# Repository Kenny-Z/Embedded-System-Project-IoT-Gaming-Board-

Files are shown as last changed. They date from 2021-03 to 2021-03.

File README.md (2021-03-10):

## WiFi-IoT-Gaming-Board
ESE516 Project Chen Chen and Wuji Zhang
This is a course project for ESE516:IoT Edge Computing. We are trying to make a Gaming Board from hardware to software.
The repository consists of the altium project, and the software project is coming along the semester.
## 3D model for Altium Project
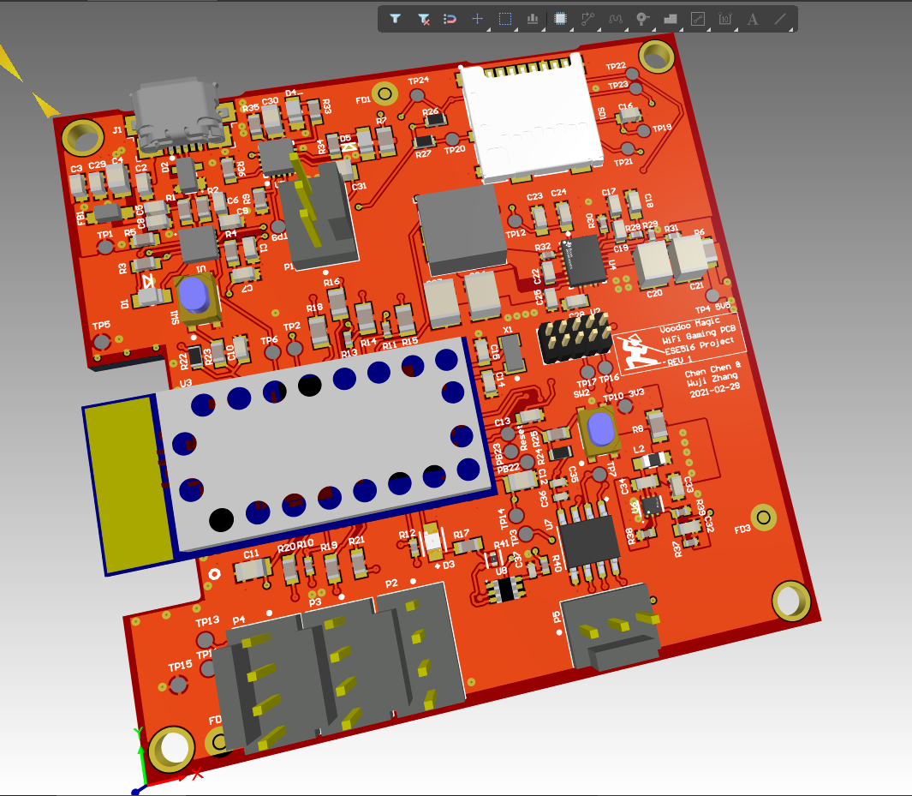
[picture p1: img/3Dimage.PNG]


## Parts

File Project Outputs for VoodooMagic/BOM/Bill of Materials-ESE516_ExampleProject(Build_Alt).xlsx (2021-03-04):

Line # | Description | Designator | Quantity | Name | Manufacturer 1 | Manufacturer Part Number 1 | Manufacturer Lifecycle 1 | Supplier 1 | Supplier Part Number 1 | Supplier Unit Price 1 | Supplier Subtotal 1
 |  |  | 0 | Keypad | DNP | DNP | DNP | Digi-Key | 1528-2712-ND | 0 | 0
 |  |  | 0 | OLED Screen | DNP | DNP | DNP | Digi-Key | 1568-1819-ND | 0 | 0
16 | CAP 100nF 16V ±10% 0603 (1608 Metric) Thickness 1mm SMD | C1, C3, C7, C16 | 4 | CAP 100nF 16V 0603(1608) | Yageo | CC0603KRX7R7BB104 | Volume Production | Digi-Key | 311-1088-6-ND | 0.1 | 0.4
7 | CAP 10nF 16V ±10% 0603 (1608 Metric) Thickness 1mm SMD | C2 | 1 | CAP 10nF 16V 0603(1608) | Yageo | CC0603KRX7R7BB103 | Volume Production | Digi-Key | 311-3369-1-ND | 0.1 | 0.1
5 | CAP 4.7uF 16V -20% to +80% 0805 (2012 Metric) Thickness 1.45mm SMD | C4, C30, C31 | 3 | CAP 4.7uF 16V 0805(2012) | Yageo | CC0805KKX7R8BB475 | Volume Production | Digi-Key | 311-1885-6-ND | 0.42 | 1.26
 | CAP 100pF 50V ±20% 0603 (1608 Metric) Thickness 1mm SMD | C5, C6, C8, C9, C17, C19 | 6 | CAP 100pF 50V 0603(1608) | KEMET | C0603C101M5GACTU | Volume Production | Digi-Key | 399-8981-6-ND | 0.1 | 0.6
4 | CAP 1uF 16V ±5% 0603 (1608 Metric) Thickness 1mm SMD | C10, C13, C29 | 3 | CAP 1uF 16V 0603(1608) | Yageo | CC0603KRX7R7BB105 | Volume Production | Digi-Key | 311-1446-6-ND | 0.15 | 0.45
8 | CAP 10uF 16V ±10% 0805 (2012 Metric) Thickness 1.45mm SMD | C11, C12 | 2 | CAP 10uF 16V 0805(2012) | Kyocera AVX | 0805YD106KAT2A | Volume Production | Digi-Key | 478-5165-1-ND | 0.39 | 0.78
9 | CAP 18pF 16V ±5% 0603 (1608 Metric) Thickness 1mm SMD | C14, C15 | 2 | CAP 18pF 16V 0603(1608) | KEMET | C0603C180J4GACTU | Volume Production | Digi-Key | 399-11141-1-ND | 0.25 | 0.5
 | CAP 1nF 10V ±1% 0603 (1608 Metric) Thickness 1mm SMD | C18 | 1 | CAP 1nF 10V 0603(1608) | Yageo | CC0603KRX7R7BB102 | Volume Production | Digi-Key | 311-4063-1-ND | 0.1 | 0.1
 | Cap Ceramic, 47 uF, +/- 10%, -55 to 85 degC, 2-Pin SMD (1210), RoHS, Tape and Reel | C20, C21, C26, C27 | 4 | GRM32ER61C476KE15L | Murata | GRM32ER61C476KE15L | Volume Production | Digi-Key | 490-6539-6-ND | 0.63 | 2.52
 | CAP 100nF 10V ±5% 0603 (1608 Metric) Thickness 1mm SMD | C22, C25 | 2 | CAP 100nF 10V 0603(1608) | Yageo | CC0402KRX7R7BB104 | Volume Production | Digi-Key | 311-1338-6-ND | 0.1 | 0.2
 | CAP 1uF 10V ±10% 0603 (1608 Metric) Thickness 1mm SMD | C23, C24 | 2 | CAP 1uF 10V 0603(1608) | Yageo | CC0603KPX7R8BB105 | Unknown | Digi-Key | 13-CC0603KPX7R8BB105DKR-ND | 0.26 | 0.52
 | CAP 8.2nF 10V ±5% 0603 (1608 Metric) Thickness 1mm SMD | C28 | 1 | CAP 8.2nF 10V 0603(1608) | Yageo | CC0603KRX7R9BB822 | Volume Production | Digi-Key | 311-1811-1-ND | 0.1 | 0.1
 | CAP 120pF 10V ±10% 0603 (1608 Metric) Thickness 1mm SMD | C32 | 1 | CAP 120pF 10V 0603(1608) | Yageo | CC0603KRX7R9BB121 | Volume Production | Digi-Key | 311-4094-1-ND | 0.1 | 0.1
 | Chip Capacitor, 22 uF, +/- 20%, 10 V, -55 to 85 degC, 0603 (1608 Metric), RoHS, Tape and Reel | C33 | 1 | C1608X5R1A226M080AC | TDK | C1608X5R1A226M080AC | Volume Production | Digi-Key | 445-9077-6-ND | 0.49 | 0.49
 | CAP 4.7uF 10V ±10% 0603 (1608 Metric) Thickness 0.55mm SMD | C34 | 1 | CAP 4.7uF 10V 0603(1608) | Yageo | CC0805KKX7R9BB225 | Volume Production | Digi-Key | 311-3420-6-ND | 1.06 | 1.06
 | CAP 1uF 10V ±10% 0402 (1005 Metric) Thickness 0.6mm SMD | C35 | 1 | CAP 1uF 10V 0402(1005) | Yageo | CC0603KRX7R7BB105 | Volume Production | Digi-Key | 311-1446-6-ND | 0.15 | 0.15
 | CAP 100nF 10V ±5% 0402 (1005 Metric) Thickness 0.6mm SMD | C36, C37 | 2 | CAP 100nF 10V 0402(1005) | Yageo | CC0603KRX7R8BB104 | Volume Production | Digi-Key | 311-1341-1-ND | 0.1 | 0.2
30 | LED Uni-Color Red, 100 mW, 200 mA, -55 to 85 degC, 2-Pin SMD, RoHS, Tape and Reel | D1, D4 | 2 | LTST-C170CKT | Vishay Lite-On | LTST-C170CKT | Volume Production | Digi-Key | 160-1176-1-ND | 0.35 | 0.7
34 | Ultra Low Capacitance Double Rail-to-Rail ESD Protection Diode, 5.5 V, 1 pF, -40 to 85 degC, 4-Pin SOT143B, RoHS, Tape and Reel | D2 | 1 | PRTR5V0U2X,215 | Nexperia | PRTR5V0U2X,215 |  | Digi-Key | 1727-3884-6-ND | 0.48 | 0.48
 | LED RED DIFFUSED 0805 SMD | D3 | 1 | LH R974-LP-1 | Osram Opto | LH R974-LP-1 | Volume Production | Digi-Key | 475-1415-1-ND | 0.26 | 0.26
31 | LED Uni-Color Green, 100 mW, 120 mA, -55 to 85 degC, 2-Pin SMD, RoHS, Tape and Reel | D5 | 1 | LTST-C170GKT | Vishay Lite-On | LTST-C170GKT | Volume Production | Digi-Key | 160-1179-1-ND | 0.3 | 0.3
24 | Chip Ferrite Bead for Power Lines, 220 Ohm, 2000 mA, -55 to 125 degC, 2 x 1.25 x 1.05 mm SMD, Tape and Reel | FB1 | 1 | BLM21PG221SN1D | Murata | BLM21PG221SN1D | Volume Production | Digi-Key | 490-1054-6-ND | 0.1 | 0.1
39 | Connector; USBMicro-B,Reverse type, SMT; 5 Position; Right Angle | J1 | 1 | ZX62R-B-5P | Hirose | ZX62R-B-5P(30) | Volume Production | Digi-Key | H125274CT-ND | 1.02 | 1.02
 | BOURNS - SRP6540-1R0M - Cewka mocy (SMD), 1 µH, 12 A, Osloniete, 13.5 A, Seria SRP6540, 7.2mm x 6.5mm x 4mm | L1 | 1 | 1uH | Bourns | SRP6540-1R0M | Volume Production | Digi-Key | SRP6540-1R0MCT-ND | 1.36 | 1.36
 | FIXED IND 470NH 1.2A 90 MOHM SMD | L2 | 1 | 470nH | Vishay Dale | IHLP1212AEERR47M11 | Volume Production | Digi-Key | 541-1330-6-ND | 1.26 | 1.26
20 | Male Header, Pitch 2.54 mm, 1 x 3 Position, Height 10.03 mm, Tail Length 3.56 mm, -55 to 105 degC | P1, P5 | 2 | 640456-3 | Molex | 22-11-2032 | Volume Production | Digi-Key | WM2701-ND | 0.53 | 1.06
 | Male Header, Pitch 2.54 mm, 1 x 4 Position, Height 10.03 mm, Tail Length 3.56 mm, RoHS, Bulk | P2, P3, P4 | 3 | 640456-4 | TE Connectivity | 640456-4 | Volume Production | Digi-Key | A1922-ND | 0.24 | 0.72
1 | 0.1" Pad | PB22, PB23, Reset, TP3, TP4 5V5, TP7, TP10 3V3, TP11, TP12, TP13, TP14, TP15, TP16, TP17, TP19, TP20, TP21, TP22, TP23, TP24 | 20 | 0.1" Pad | DNP | DNP | DNP | DNP | DNP | DNP
11 | 27R 0.1W 1% 0603 (1608 Metric) SMD | R1, R2, R19, R20, R21 | 5 | 27R 1% 0603(1608) | Stackpole Electronics | RMCF0603JT27R0 | Volume Production | Digi-Key | RMCF0603JT27R0DKR-ND | 0.014 | 0.14
3 | 1K 0.1W 1% 0603 (1608 Metric) SMD | R3, R5, R9, R17, R33, R34 | 6 | 1K 1% 0603(1608) | Stackpole Electronics | RMCF0603FG1K00 | Volume Production | Digi-Key | RMCF0603FG1K00CT-ND | 0.016 | 0.16
28 | Jumper 0603 (1608 Metric) | R4 | 1 | Jumper 0603(1608) | Yageo | RC0603JR-070RL | Volume Production | Digi-Key | 311-0.0GRCT-ND | 0.1 | 0.1
29 | Jumper 0805 (2012 Metric) | R6, R7, R8, R14, R15, R16, R18 | 7 | Jumper 0805(2012) | Yageo | RC0805JR-070RL | Volume Production | Digi-Key | 311-0.0ARDKR-ND | 0.031 | 0.31
 | 4K7 0.063W 1% 0402 (1005 Metric) SMD | R10, R11, R12, R13 | 4 | 4K7 1% 0402(1005) | Stackpole Electronics | RMCF0402FT4K70 | Volume Production | Arrow Electronics | RMCF0402FT4K70 | 0.021 | 0.084
 | Chip Resistor, 10 KOhm, +/- 1%, 0.1 W, -55 to 155 degC, 0603 (1608 Metric), RoHS, Tape and Reel | R22, R24, R26, R27 | 4 | ERJ3EKF1002V | Stackpole Electronics | RMCF0402FT10K0 | Volume Production | Digi-Key | RMCF0402FT10K0CT-ND | 0.014 | 0.14
17 | 100R 0.1W 1% 0603 (1608 Metric) SMD | R23, R25 | 2 | 100R 1% 0603(1608) | Stackpole Electronics | RMCF0603FG100R | Volume Production | Digi-Key | RMCF0603FG100RCT-ND | 0.016 | 0.16
 | 23K7 0.063W 1% 0402 (1005 Metric) SMD | R28 | 1 | 23K7 1% 0402(1005) | Stackpole Electronics | RMCF0603FT23K7 | Volume Production | Digi-Key | RMCF0603FT23K7DKR-ND | 0.1 | 0.1
 | 86K6 0.063W 1% 0402 (1005 Metric) SMD | R29 | 1 | 86K6 1% 0402(1005) | Stackpole Electronics | RMCF0402FT86K6 | Volume Production | Digi-Key | RMCF0402FT86K6DKR-ND | 0.1 | 0.1
 | 140K 0.063W 1% 0402 (1005 Metric) SMD | R30 | 1 | 140K 1% 0402(1005) | Stackpole Electronics | RMCF0402FT140K | Volume Production | Digi-Key | 738-RMCF0402FT140KCT-ND | 0.1 | 0.1
 | 309K 0.063W 1% 0402 (1005 Metric) SMD | R31 | 1 | 309K 1% 0402(1005) | Stackpole Electronics | RMCF0402FT309K | Volume Production | Digi-Key | RMCF0402FT309KDKR-ND | 0.1 | 0.1
 | 453K 0.063W 1% 0402 (1005 Metric) SMD | R32, R37 | 2 | 453K 1% 0402(1005) | Stackpole Electronics | RMCF0402FT453K | Volume Production | Digi-Key | RMCF0402FT453KDKR-ND | 0.014 | 0.14
2 | 1K13 0.1W 1% 0603 (1608 Metric) SMD | R35, R36 | 2 | 1K13 1% 0603(1608) | Stackpole Electronics | RMCF0603FT1K13 | Volume Production | Digi-Key | RMCF0603FT1K13DKR-ND | 0.016 | 0.16
 | 100K 0.063W 1% 0402 (1005 Metric) SMD | R38, R39 | 2 | 100K 1% 0402(1005) | Stackpole Electronics | RMCF0402FT100K | Volume Production | Digi-Key | RMCF0402FT100KDKR-ND | 0.014 | 0.14
 | 10R 0.063W 1% 0402 (1005 Metric) SMD | R40 | 1 | 10R 1% 0402(1005) | Stackpole Electronics | RMCF0402JT10R0 | Volume Production | Arrow Electronics | RMCF0402JT10R0 | 0.0132 | 0.0132
 | RES Thick Film, 10kΩ, 1%, 0.063W, 100ppm/°C, 0402 | R41 | 1 | CRCW040210K0FKEE | Stackpole Electronics | RMCF0402FT10K0 | Volume Production | Digi-Key | RMCF0402FT10K0DKR-ND | 0.1 | 0.1
19 | Micro SD Card, RA, -25 to 85 degC, 8-Pin SMD, RoHS, Tape and Reel | SD1 | 1 | 104031-0811 | Molex | 1040310811 | Volume Production | Digi-Key | WM6357DKR-ND | 1.83 | 1.83
 | SWITCH TACTILE SPST-NO 0.05A 16V | SW1, SW2 | 2 | PTS810 SJG 250 SMTR LFS | ITT C&K | PTS810SJG250SMTRLFS | Volume Production | Digi-Key | CKN10504CT-ND | 0.37 | 0.74
27 | FT234XD USB to BASIC UART IC, -40 to +85 degC, 12-Pin DFN, Pb-Free, Tape and Reel | U1 | 1 | FT234XD-R | FTDI | FT234XD-R | Volume Production | Digi-Key | 768-1178-1-ND | 2.04 | 2.04
21 | CONN HEADER 10POS UNSHD VERT T/H | U2 | 1 | 20021111-00010T4LF | Amphenol FCI | 20021111-00010T4LF | Volume Production | Digi-Key | 609-3712-ND | 0.73 | 0.73
36 | RF TXRX MODULE WIFI TRACE ANT | U3 | 1 | SAMW25H18-MR510PB | Microchip / Atmel | ATSAMW25H18-MR510PB | Volume Production | Digikey | ATSAMW25H18-MR510PB-ND
 | IC REG BOOST ADJ 10A 20VQFN | U4 | 1 | TPS61088RHLT | Texas Instruments | TPS61088RHLT | New Product | Digi-Key | 296-42129-1-ND | 4.55 | 4.55
 | USB-Friendly Li-Ion Battery Charger and Power-Path Management IC, Vout 5.5 V, 4.3 V, -40 to 85 degC, 16-pin QFN (RGT), Green (RoHS & no Sb/Br) | U5 | 1 | BQ24075RGTR | Texas Instruments | BQ24075RGTR | Volume Production | Digi-Key | 296-38874-6-ND | 2.19 | 2.19
 | 2.4V-5.5V input, 4A step-down converter with 1% Accuracy in 1.5mm x 1.5mm QFN 6-VSON-HR -40 to 125 | U6 | 1 | TPS62827DMQR | Texas Instruments | TPS62827DMQR |  | Digi-Key | 296-TPS62827DMQRCT-ND
 | Sensor Controller Capacitive 3-CH I2C 8-Pin SOIC T/R | U7 | 1 | I2C Touch Sensor | Microchip | CAP1203-1-SN-TR | Not Recommended for New Design | Digi-Key | CAP1203-1-SN-CT-ND | 0.55 | 0.55
 | HIGH ACCURACY AMBIENT LIGHT SENS | U8 | 1 | I2C Light Sensor | Vishay Semiconductors | VEML6030-GS15 |  | Digi-Key | VEML6030-GS15CT-ND | 2 | 2
22 | Crystal, 32.768 kHz, 12.5 pF, -40 to 85 degC, SMD Low Profile 3.2 x 1.5 x 0.9 mm, Tape and Reel | X1 | 1 | ABS07-32.768KHz-T | Micro Crystal | CC7V-T1A-32.768KHZ-12.5PF-20PPM-TA-QC |  | Digi-Key | 2195-CC7V-T1A-32.768KHZ-12.5PF-20PPM-TA-QCCT-ND | 0.61 | 0.61

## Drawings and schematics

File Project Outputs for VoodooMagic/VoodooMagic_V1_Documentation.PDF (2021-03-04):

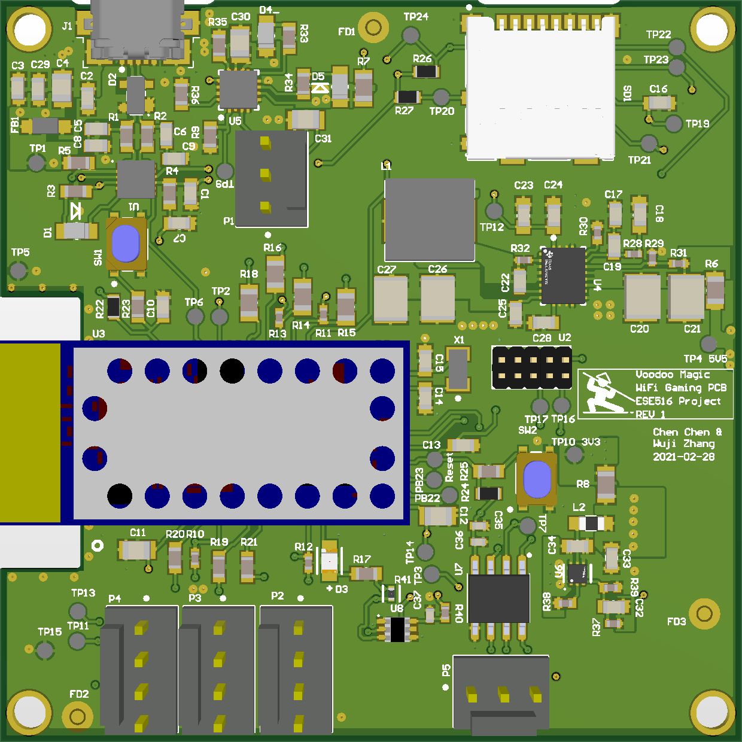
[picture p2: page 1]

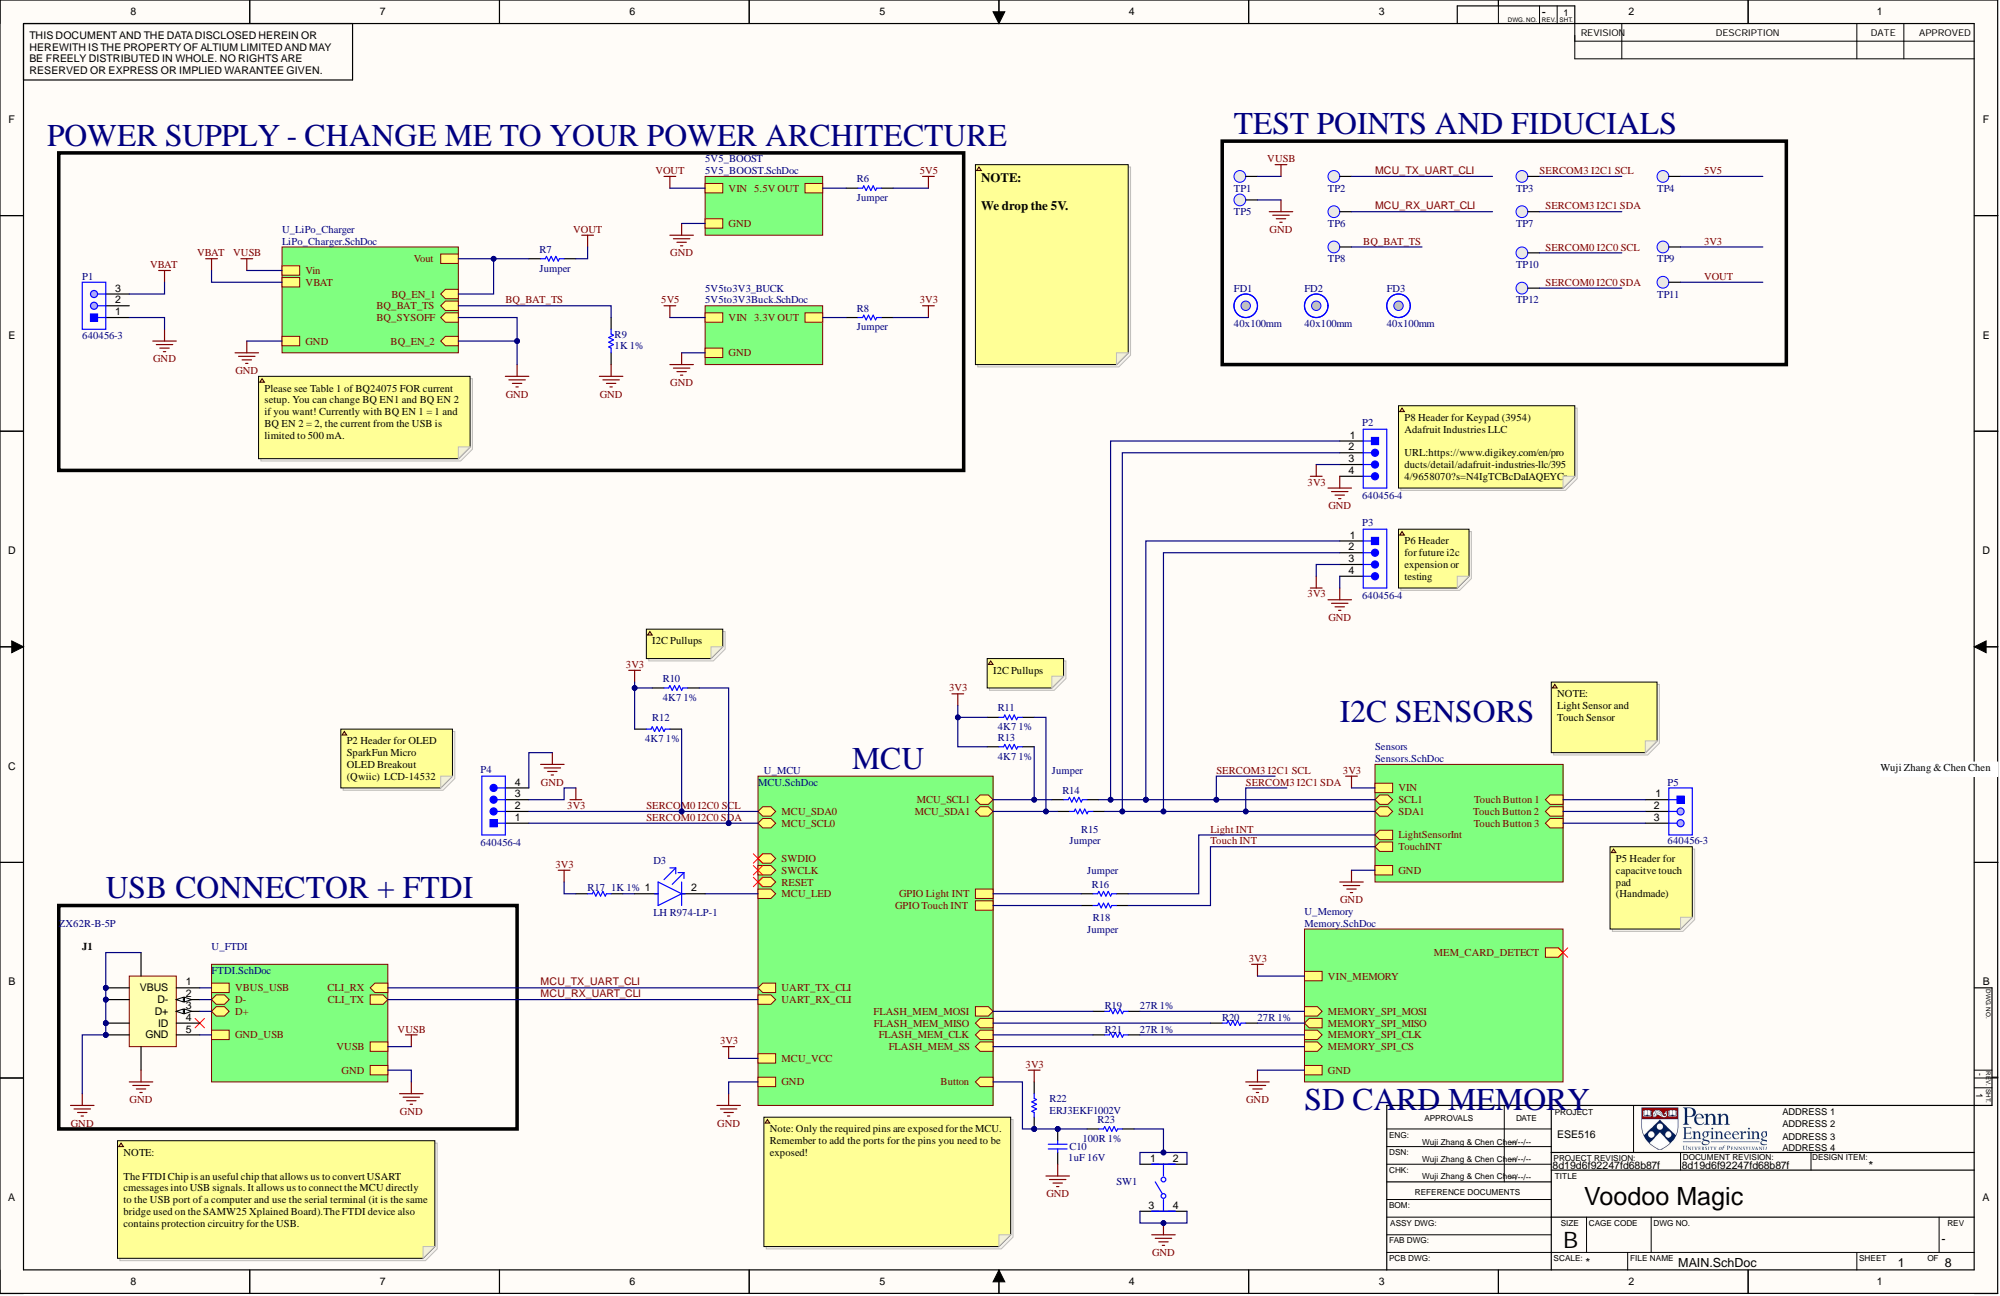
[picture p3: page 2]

DWG. NO. | -REV. | 1 SHT.

THIS DOCUMENT AND THE DATA DISCLOSED HEREIN OR HEREWITH IS THE PROPERTY OF ALTIUM LIMITED AND MAY BE FREELY DISTRIBUTED IN WHOLE. NO RIGHTS ARE RESERVED OR EXPRESS OR IMPLIED WARANTEE GIVEN. POWER SUPPLY - CHANGE ME TO YOUR POWER ARCHITECTURE | TEST POINTS AND FIDUCIALS | REVISION | DESCRIPTION | DATE | APPROVED

GND
Please see Table 1 of BQ24075 FOR current
setup. You can change BQ EN1 and BQ EN 2
if you want! Currently with BQ EN 1 = 1 and
BQ EN 2 = 2, the current from the USB is
limited to 500 mA.

URL:https://www.digikey.com/en/pro
ducts/detail/adafruit-industries-llc/395
4/9658070?s=N4IgTCBcDaIAQEYCs

SERCOM3 I2C1 SCL | 3

Wuji Zhang & Chen Chen

REV. SHT. DWG. NO.

Note: Only the required pins are exposed for the MCU.
Remember to add the ports for the pins you need to be
exposed!

DSN: Wuji Zhang & Chen Chen | --/--/--

8d19d6f92247fd68b87f | DOCUMENT REVISION: 8d19d6f92247fd68b87f | DESIGN ITEM: * PROJECT REVISION:

CHK: Wuji Zhang & Chen Chen | --/--/--

The FTDI Chip is an useful chip that allows us to convert USART
cmessages into USB signals. It allows us to connect the MCU directly
to the USB port of a computer and use the serial terminal (it is the same
bridge used on the SAMW25 Xplained Board).The FTDI device also
contains protection circuitry for the USB.

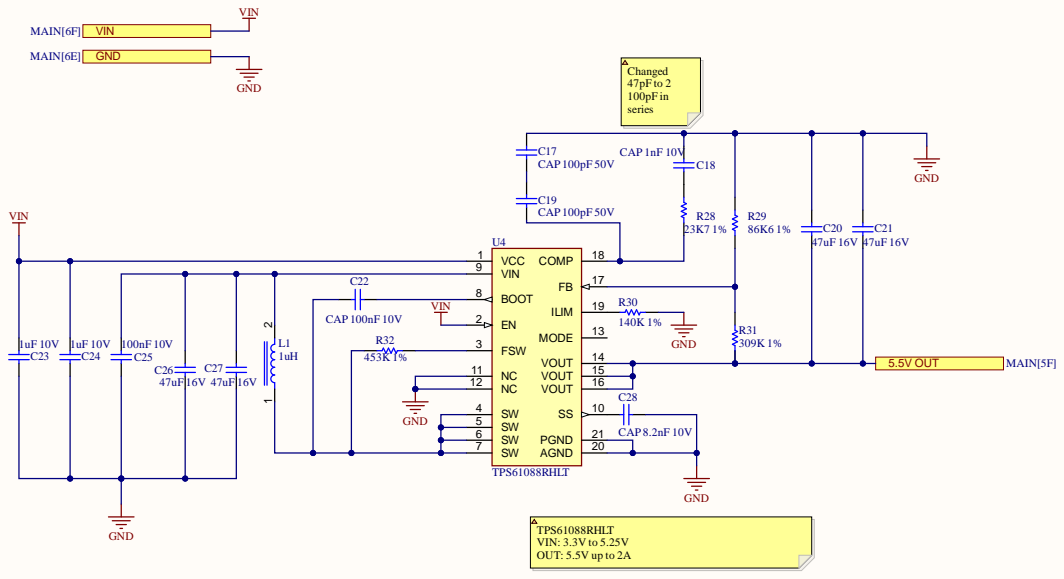
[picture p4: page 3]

DWG. NO. | -REV. | 2 SHT.

THIS DOCUMENT AND THE DATA DISCLOSED HEREIN OR HEREWITH IS THE PROPERTY OF ALTIUM LIMITED AND MAY BE FREELY DISTRIBUTED IN WHOLE. NO RIGHTS ARE RESERVED OR EXPRESS OR IMPLIED WARANTEE GIVEN. | | REVISION | DESCRIPTION | DATE | APPROVED

R32
453K 1% | NC 11

REV. SHT. DWG. NO.

DATE | PROJECT * | ADDRESS 1 ADDRESS 2 APPROVALS ADDRESS 3 ADDRESS 4

ENG: * | --/--/--

DSN: Wuji Zhang | --/--/--

8d19d6f92247fd68b87f | DOCUMENT REVISION: 8d19d6f92247fd68b87f | DESIGN ITEM: * PROJECT REVISION:

CHK: Wuji Zhang | --/--/--

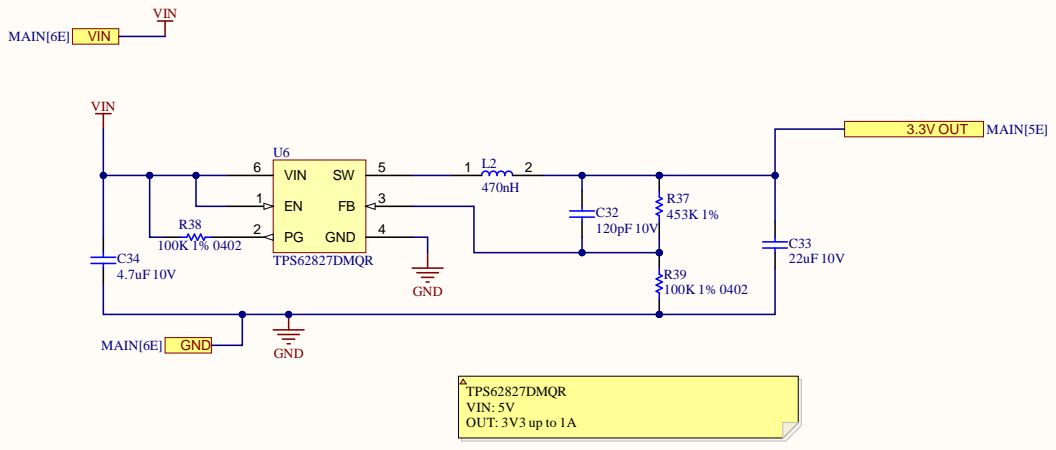
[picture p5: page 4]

DWG. NO. | -REV. | 3 SHT.

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

REV. SHT. DWG. NO.

DATE | PROJECT * | ADDRESS 1 ADDRESS 2 APPROVALS ADDRESS 3 ADDRESS 4

ENG: Wuji Zhang | --/--/--

DSN: Wuji Zhang | --/--/--

8d19d6f92247fd68b87f | DOCUMENT REVISION: 8d19d6f92247fd68b87f | DESIGN ITEM: * PROJECT REVISION:

CHK: Wuji Zhang | --/--/--

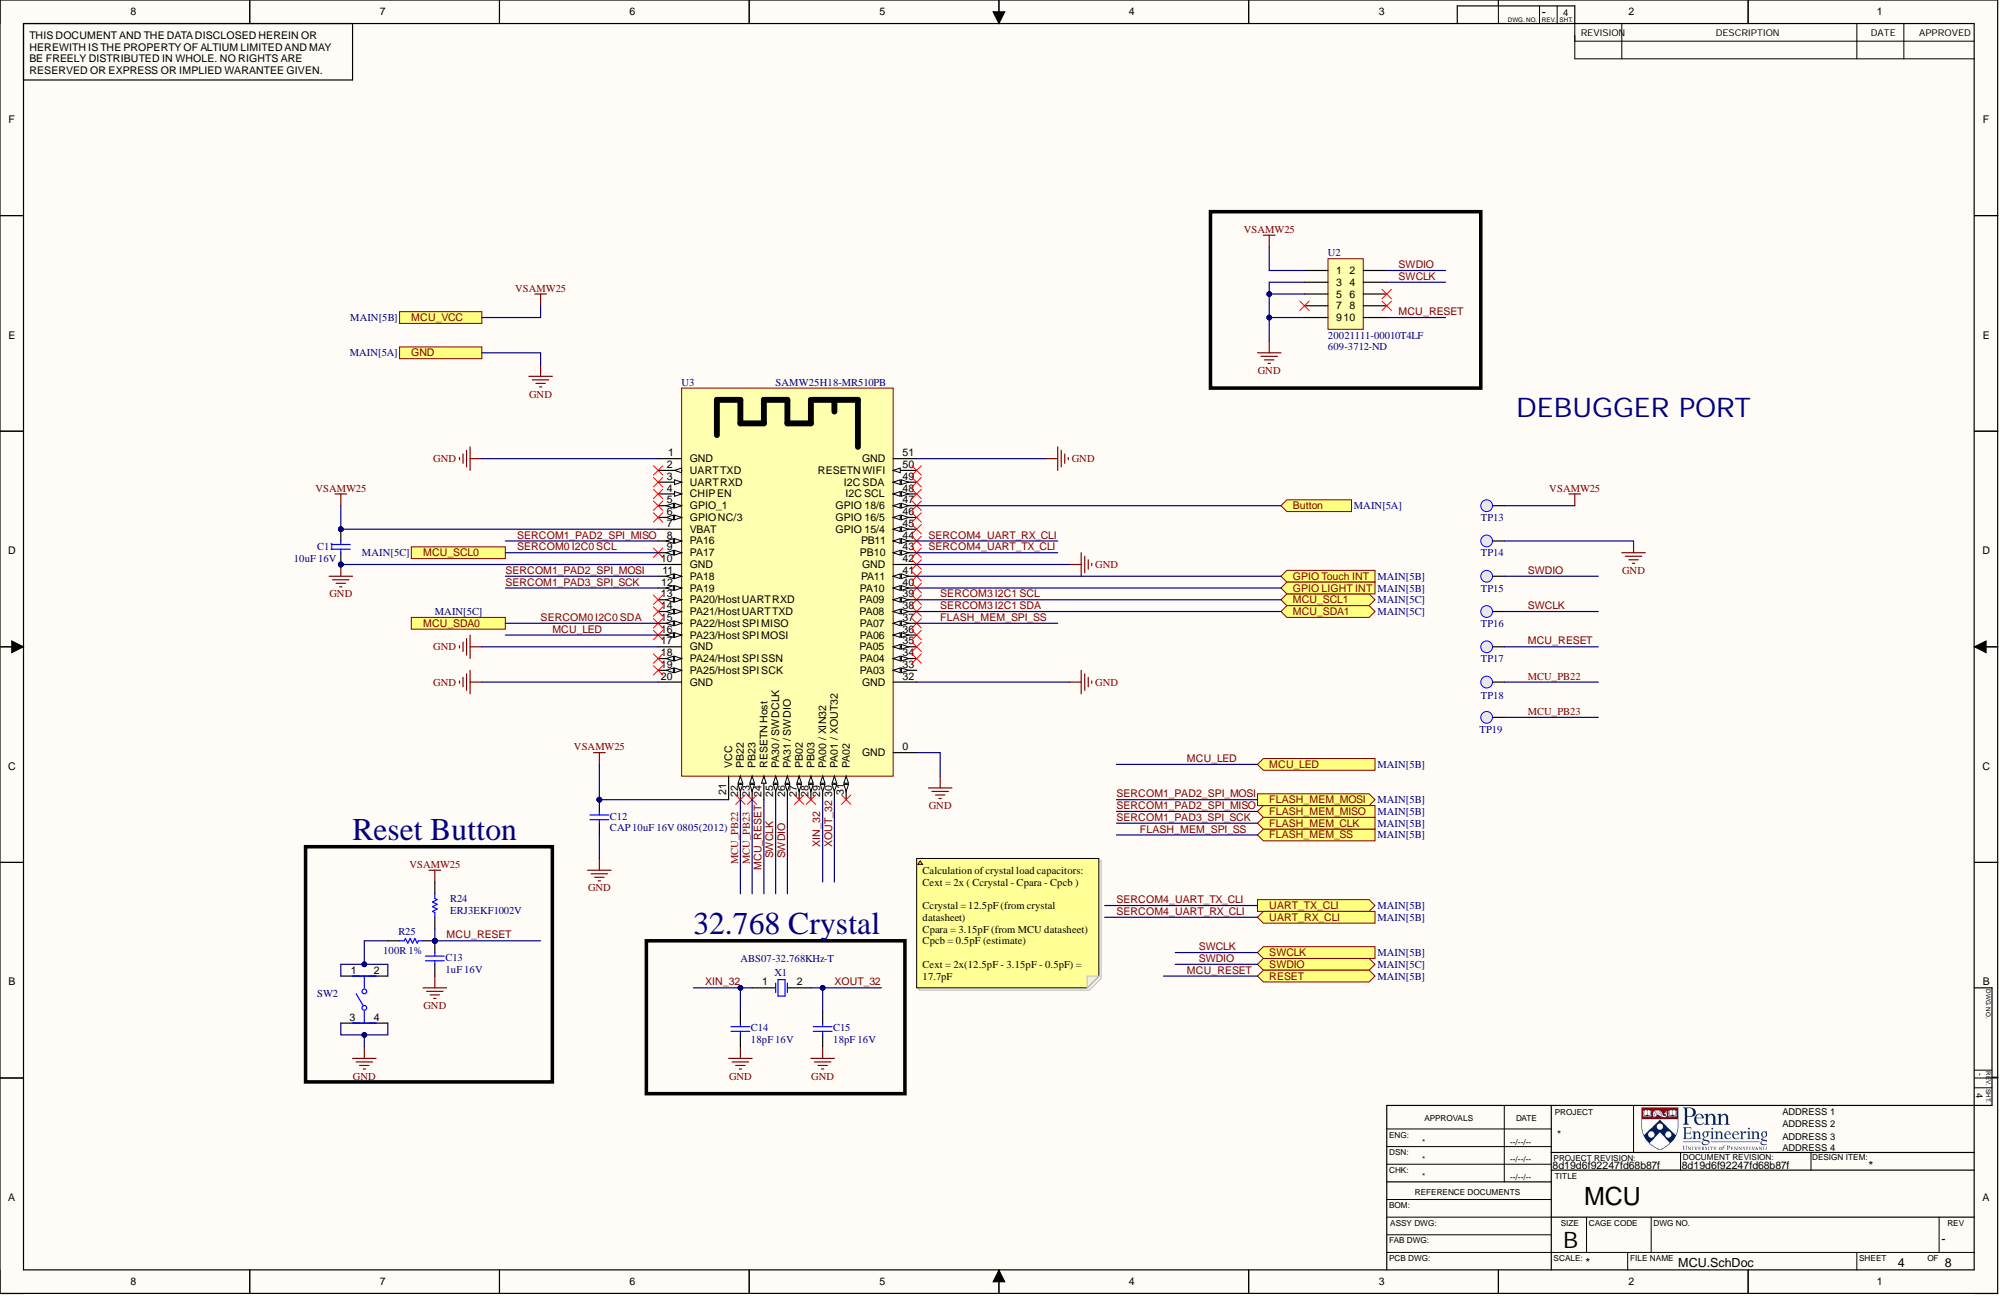
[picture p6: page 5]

DWG. NO. | -REV. | 4 SHT.

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

GPIO Touch INT MAIN[5B]
GPIO LIGHT INT MAIN[5B]

Calculation of crystal load capacitors:
Cext = 2x ( Ccrystal - Cpara - Cpcb )

Ccrystal = 12.5pF (from crystal
datasheet)
Cpara = 3.15pF (from MCU datasheet)
Cpcb = 0.5pF (estimate)

REV. SHT. DWG. NO.

DATE | PROJECT * | ADDRESS 1 ADDRESS 2 APPROVALS ADDRESS 3 ADDRESS 4

ENG: * | --/--/--

DSN: * | --/--/--

8d19d6f92247fd68b87f | DOCUMENT REVISION: 8d19d6f92247fd68b87f | DESIGN ITEM: * PROJECT REVISION:

CHK: * | --/--/--

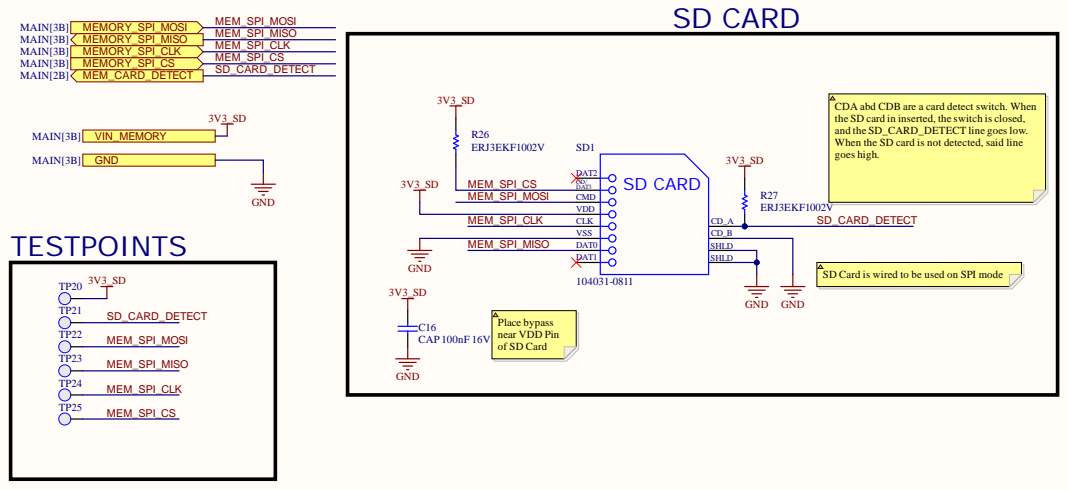
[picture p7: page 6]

DWG . N O . | -R E V | 5 . S H T.

T H IS DOC U MEN T AN D T HE ATA ISCLOSED HEREI N OR HEREW I T H IS T HE PROPER TY OF ALT I U M LI M I TED AN M AY BE F REELY IST R IBU TED I N W HOLE. NO R IGH TS ARE RESERVED OR EXPRESS OR I MPLIED WARAN TEE GIVEN . | | REVISI O N | DESC R IPT I O N | DAT E | APPR OVED

REV. SHT. DWG. NO.

DATE | PRO JECT * | AD D RESS 1 2 APPROVALS AD D RESS AD D RESS 3 AD D RESS 4

ENG : Wu j i Zh a n g | --/--/--

DSN: Wu j i Zh a n g | --/--/--

8d19d6f92247fd68b 8 7 f | DOCUMENT REVISION: 8d19d6f92247fd68b 8 7 f | DESIGN ITEM: * PROJECT REVISION:

CHK: Wu j i Zh a n g | --/--/--

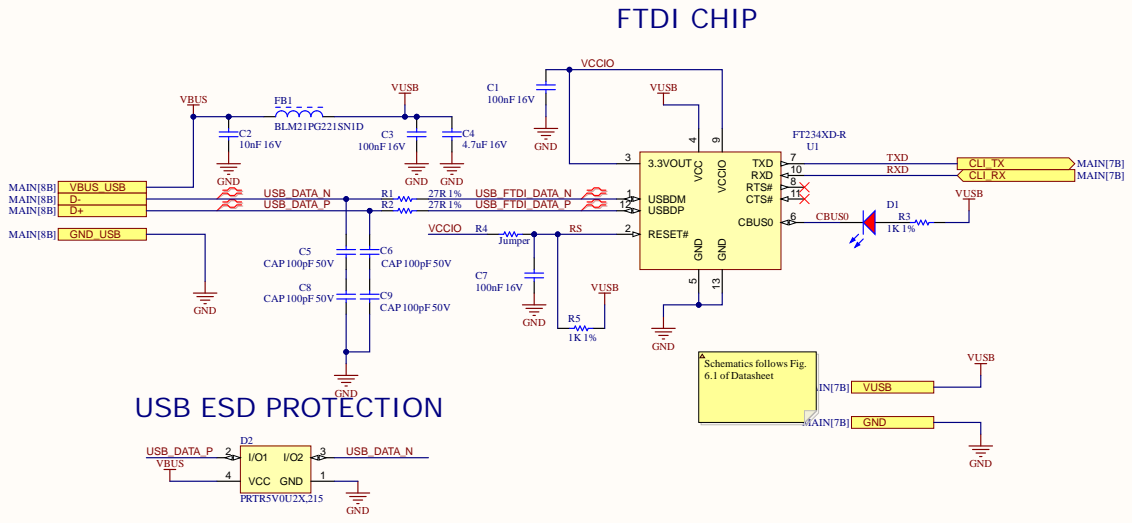
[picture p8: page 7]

DWG. NO. | -REV. | 6 SHT.

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

REV. SHT. DWG. NO.

DATE | PROJECT * | ADDRESS 1 ADDRESS 2 APPROVALS ADDRESS 3 ADDRESS 4

ENG: Wuji Zhang | --/--/--

DSN: Wuji Zhang | --/--/--

8d19d6f92247fd68b87f | DOCUMENT REVISION: 8d19d6f92247fd68b87f | DESIGN ITEM: * PROJECT REVISION:

CHK: Wuji Zhang | --/--/--

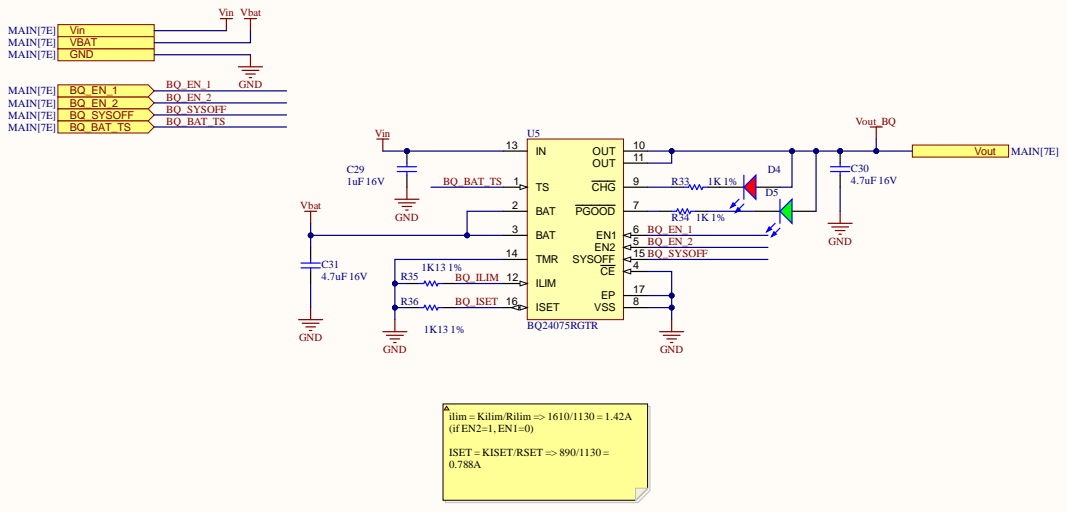
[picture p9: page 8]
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

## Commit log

2021-02-07 Version1 A2Q2
    Wuji Zhang
    [ESE516A2.PcbLib, ESE516A2.SchLib, ESE516_ExampleLayoutProject_.PrjPcb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]
2021-02-09 123
    123
    [5.SchDoc, 5V5_BOOST.SchDoc, 5Vto3V3Buck.SchDoc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]
2021-02-09 new
    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
    [ESE516_ExampleLayoutProject_.PrjPcb, Sensors.SchDoc]
2021-02-09 MCU sensor
    [5.5Vto5VBuck.SchDoc, ESE516_ExampleLayoutProject_.PrjPcb, MAIN.SchDoc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]
2021-02-09 changed power arc
    [5V5_BOOST.SchDoc, 5Vto3V3Buck.SchDoc, MAIN.SchDoc]
2021-02-10 added pull up resistors and jumpers
    [MAIN.SchDoc, Sensors.SchDoc]
2021-02-10 updated pull up resistors and jumpers
    [MAIN.SchDoc]
2021-02-10 changed i2c to bidirectional
    [Sensors.SchDoc]
2021-02-10 Added test-points and a button
    [MAIN.SchDoc, MCU.SchDoc]
2021-02-10 Revert "Added test-points and a button"
    This reverts commit 3adceac150bba514b88dde3d941b7ec402dccbc6.
    [MAIN.SchDoc, MCU.SchDoc]
2021-02-10 Revert "Merge branch 'main' of https://github.com/Kenny-Z/Voodoo_Magic into main"
    This reverts commit 856beccacb5d0c5afcd0d452565934a0bd5b225c, reversing
    changes made to 3adceac150bba514b88dde3d941b7ec402dccbc6.
    [Sensors.SchDoc]
2021-02-10 added pull up resistors/ test points/ button
    [MAIN.SchDoc, MCU.SchDoc, Sensors.SchDoc]
2021-02-10 set as a whole project with hierarchy
    [MAIN.SchDoc]
2021-02-10 numbered schematic sheets
    [5.5Vto5VBuck.SchDoc, 5V5_BOOST.SchDoc, 5Vto3V3Buck.SchDoc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]
2021-02-16 added button debounce and renumbered sheets
    [MAIN.SchDoc, MCU.SchDoc, VoodooMagic.PrjPcb]
2021-02-16 I2C PULL UP
    [MAIN.SchDoc, Sensors.SchDoc]
2021-02-16 changed inductor in 5V buck
    MLP2012SR47MT0S1 is back in stock (470nH)
    [5.5Vto5VBuck.SchDoc, 5V5_BOOST.SchDoc, 5Vto3V3Buck.SchDoc]
2021-02-17 changed BOM
    [FTDI.SchDoc]
2021-02-17 bom partial done
2021-02-17 BOM completed
2021-02-17 changed LED in BOM
2021-02-23 A4 USB
    [MAIN.SchDoc, VoodooMagic.PrjPcb]
2021-02-23 VBAT TQ24075
    [MAIN.SchDoc, VoodooMagic.PrjPcb]
2021-02-23 5V BUCK
2021-02-25 violation under 40
    [Memory.SchDoc]
2021-02-26 Remove out-of-stock components
    [5.5Vto5VBuck.SchDoc, 5V5_BOOST.SchDoc, 5Vto3V3Buck.SchDoc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]
2021-02-28 Feedback done
    [MCU.SchDoc, Memory.SchDoc]
2021-03-01 gogogo Error: BOM
    [VoodooMagic.PrjPcb]
2021-03-03 replaced 3 pin header
2021-03-03 modified draftsman file
    [MAIN.SchDoc, MCU.SchDoc, Memory.SchDoc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]
2021-03-03 Some rules checking
    [VoodooMagic.PrjPcb]
2021-03-03 Components ready.
    [MAIN.SchDoc, MCU.SchDoc, Memory.SchDoc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]
2021-03-03 draftsman file added
    [VoodooMagic.PrjPcb]
2021-03-04 OUTPUT FILES GENERATED
    [Bill of Materials-ESE516_ExampleProject.xlsx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]
2021-03-04 Remove 5V
    [5V5_BOOST.SchDoc, 5V5to3V3Buck.SchDoc, FTDI.SchDoc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]
2021-03-04 final revision
    [Bill of Materials-ESE516_ExampleProject(Build_Alt).xlsx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]
2021-03-04 output files
    [Bill of Materials-ESE516_ExampleProject(Build_Alt).xlsx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]
